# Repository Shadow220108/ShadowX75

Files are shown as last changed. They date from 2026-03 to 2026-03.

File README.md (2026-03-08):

# ShadowX75
It is a 75% layout, mechanical keyboard with hot-swap sockets! A rotatory encoder and an OLED screen!  

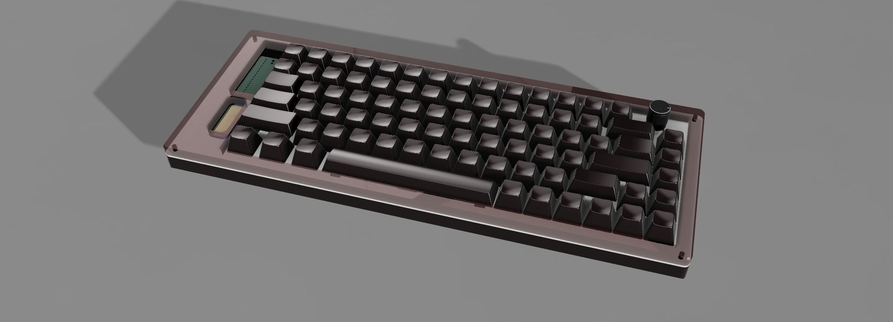
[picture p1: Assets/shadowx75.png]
ShadowX75
  

I made this project because I love keyboards. This would be my second keyboard after a split one! This version runs on QMK firmware and also has a rotatory encoder with an OLED screen  

### PCB
The PCB is designed to be compatible with Cherry MX switches and features hot-swappable kalih sockets.
| Schematics |
| --- |
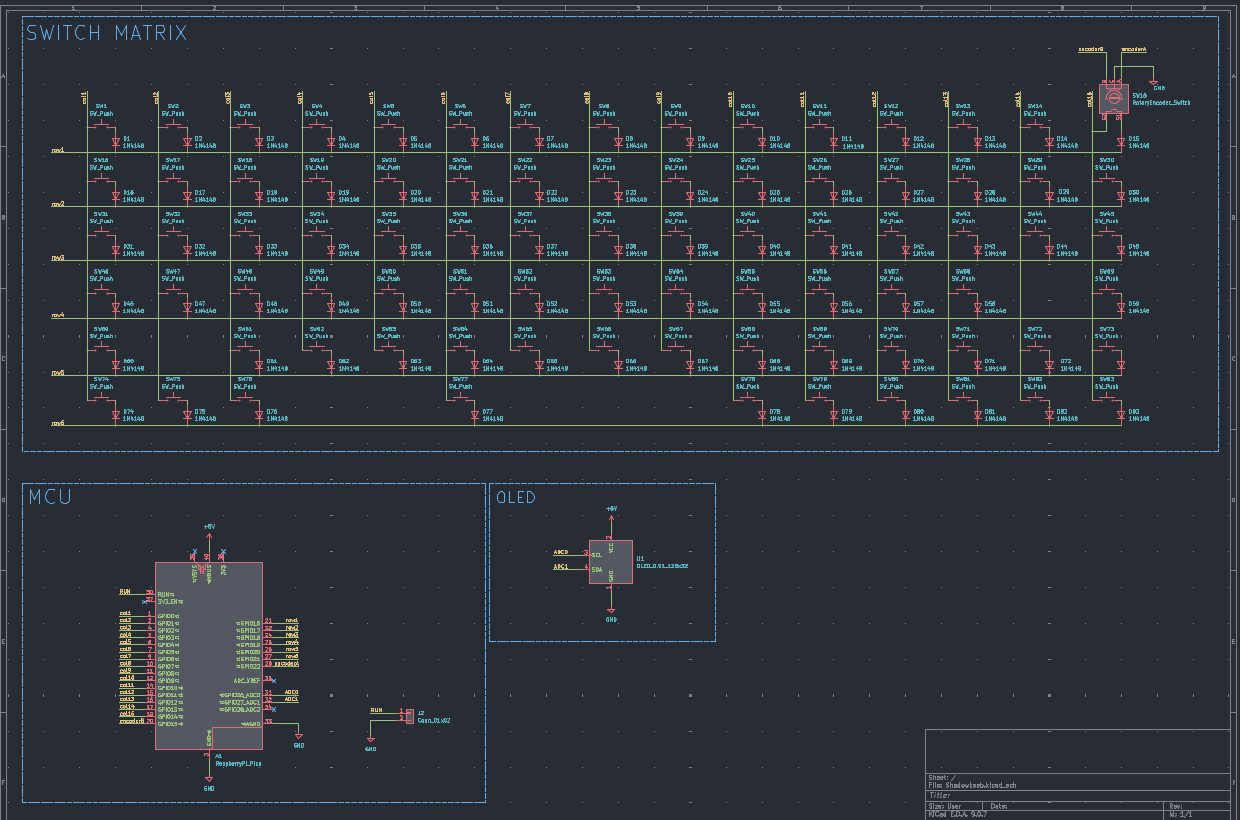
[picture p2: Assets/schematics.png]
Schematics
|  | 

| PCB (All Layers)|
| --- |
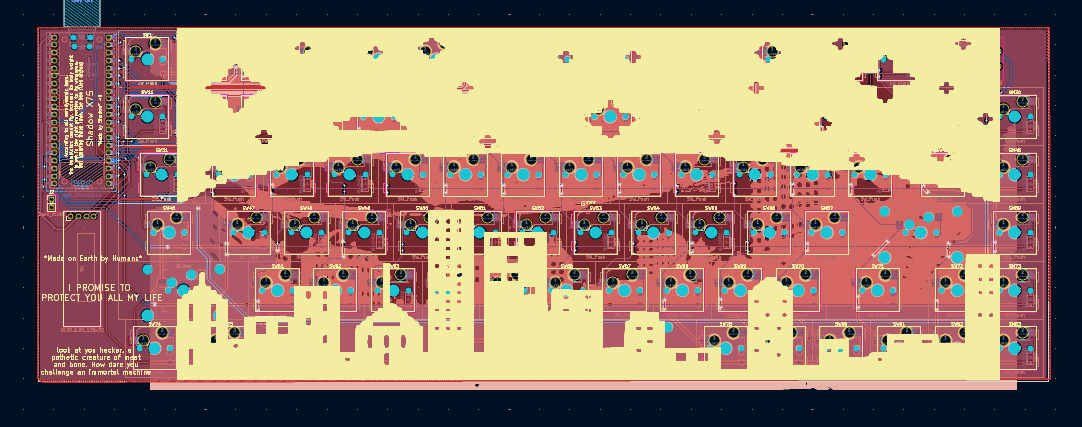
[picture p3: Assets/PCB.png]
PCB All Layers
|  |

| PCB (Without the art and zones)|
| --- |
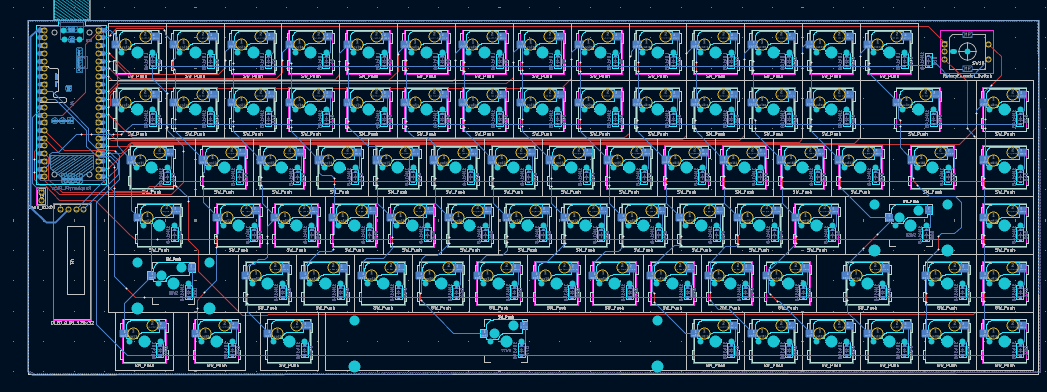
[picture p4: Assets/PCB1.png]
PCB1
|  |

| PS : Some PCB art|
| --- |
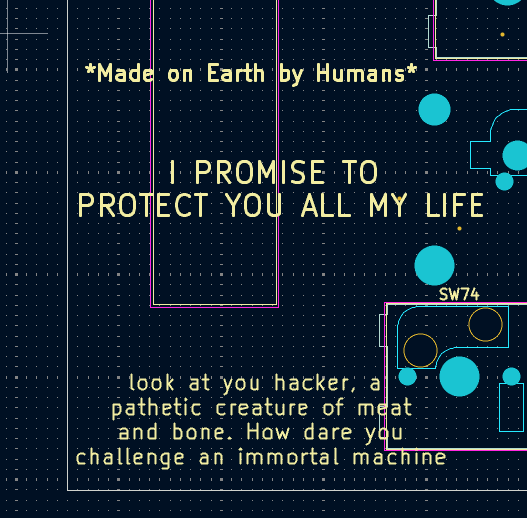
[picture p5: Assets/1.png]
|  |
| --- |
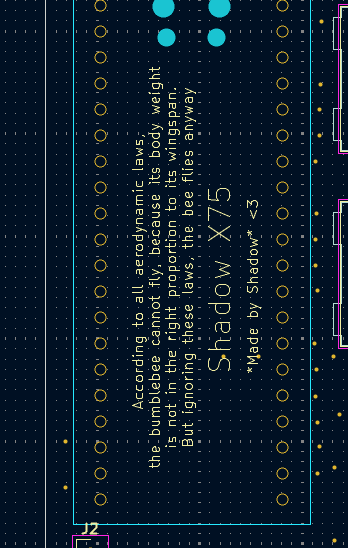
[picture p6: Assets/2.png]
|  |

## Case

The case is designed to be 3D printed and features a sandwich mount design with a 5° typing angle. The bottom case, top case, plate, and knob are all designed to be printed.

| Case Full|
| --- |
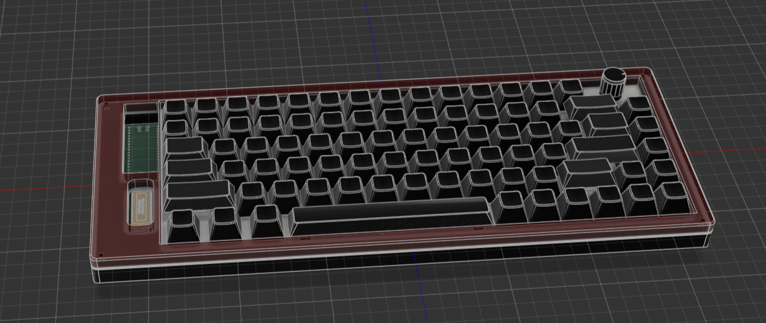
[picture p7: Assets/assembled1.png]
|  |

| Case Exploded View|
| --- |
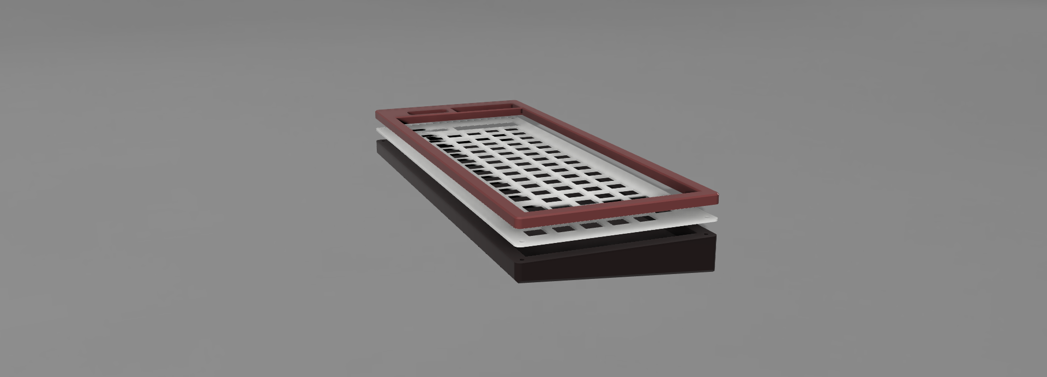
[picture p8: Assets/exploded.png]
|  |

## BOM ( I already have the parts mentioned as self sourced )
|Name |Purpose |Cost (USD)|Qty|Total (USD) |Link |Distributor |
|---|---|---|---|---|---|---|
| | | | | | | |
|Hotswap sockets |To solder to the PCB for switches |$0.11 |90 |$9.90 |[Link to Listing](https://stackskb.com/store/gateron-hotswap-sockets/)|Stackskb |
|PCB ( 5 MOQ ) |this is the main circuit board for keyboard |$40.00 |1  |$40.00 |- |JLCPCB |
|Stabilzers |To support the 2u and 6.25u keys |$0.00 |1  |$0.00 |- |Self sourced ( I already have the parts mentioned as self sourced )|
|Heatset inserts and Screws  |To attach the 3 bodies together |$0.00 |8  |$0.00 |- |Self sourced |
|Rotatory Encoder |To control volume/brightness |$0.00 |1  |$0.00 |- |Self sourced |
|OLED ( 0.91 inch ) |To display random stuff while I type |$0.00 |1  |$0.00 |- |Self sourced |
|Shipping charges |Shipping charge to get the 3d prints ( from #printing-legion )|$6.00 |1  |$6.00 |- |#printing-legion |
|Pin headers ( 1x40 ) |To solder the rpi pico to the PCB |$0.01 |1  |$0.01 |[Link to Listing](https://robu.in/product/2-54mm-1x40-pin-male-single-row-straight-short-header-strip-pack-of-3/)|robu.in |
|raspberry pi pico |This is the MCU of the keyboard |$4.50 |1  |$4.50 |[Link to Listing](https://robu.in/product/raspberry-pi-pico/)|robu.in |
|1N4148W SOD-123 1206 Diode  |Used for the matrix wiring in the keyboard |$0.01 |100|$0.92 |[Link to Listing](https://robu.in/product/1n4148w-sod-123-1206-diodereel-of-3000/)|robu.in |
|Keycap set ( Full Keyboard )|To add on the switches |$14.14 |1  |$14.14 |[Link to Listing](https://stackskb.com/store/veekos-gradient-keycaps-cherry-profile-135-keys/?attribute_pa_colour=rose-latte)|Stackskb |
|Switches |To press the keys |$0.26 |90 |$23.40 |[Link to Listing](https://stackskb.com/store/akko-piano-pro-switch-pack-of-45/)|Stackskb |
| | | | | | | |
| | | | |Total Estimated Cost (USD):$98.87| | |

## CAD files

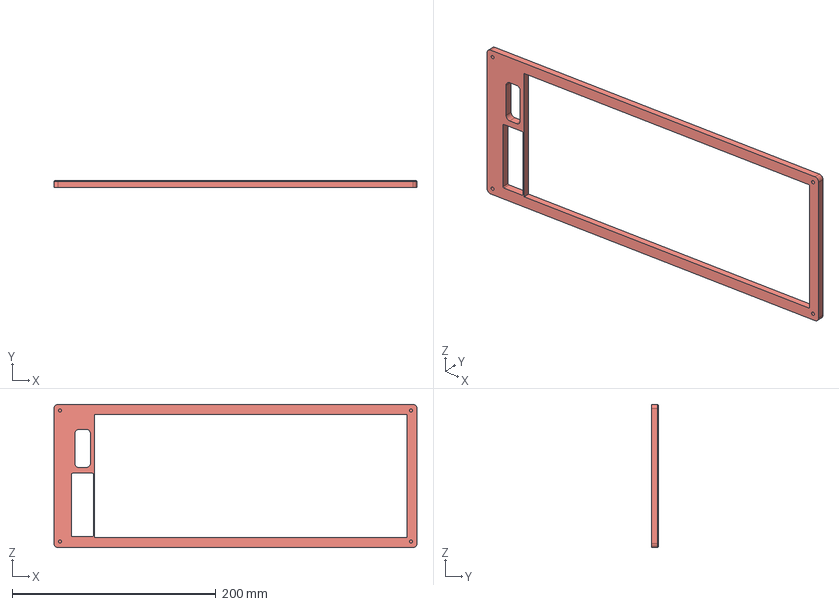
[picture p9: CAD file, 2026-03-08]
CAD/top.step
356.5 x 7.00 x 140.7 mm

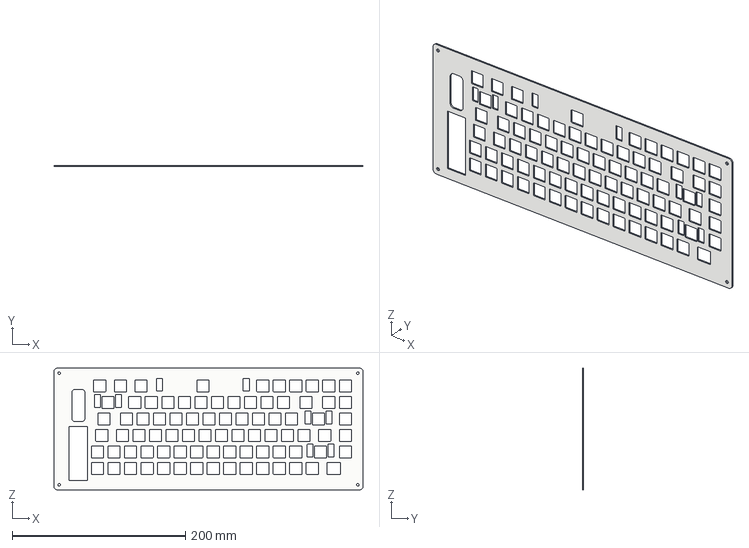
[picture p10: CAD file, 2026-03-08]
CAD/middle.step
356.5 x 1.50 x 140.7 mm

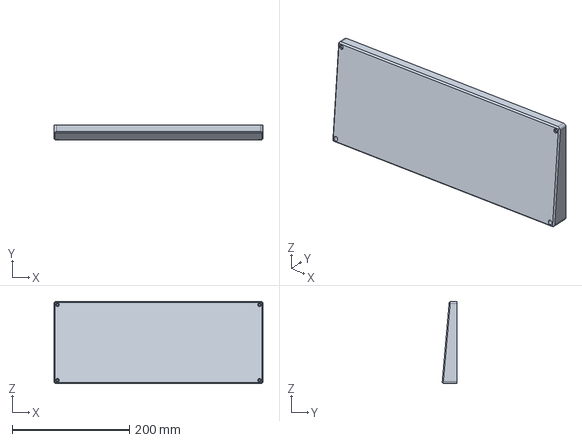
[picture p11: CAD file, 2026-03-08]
CAD/bottom.step
356.5 x 25.1 x 140.7 mm

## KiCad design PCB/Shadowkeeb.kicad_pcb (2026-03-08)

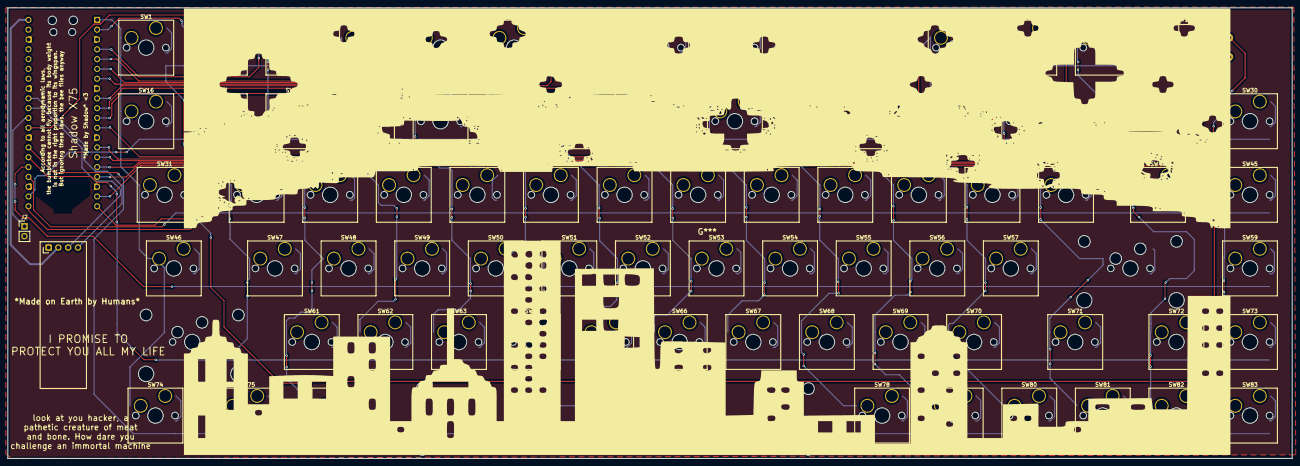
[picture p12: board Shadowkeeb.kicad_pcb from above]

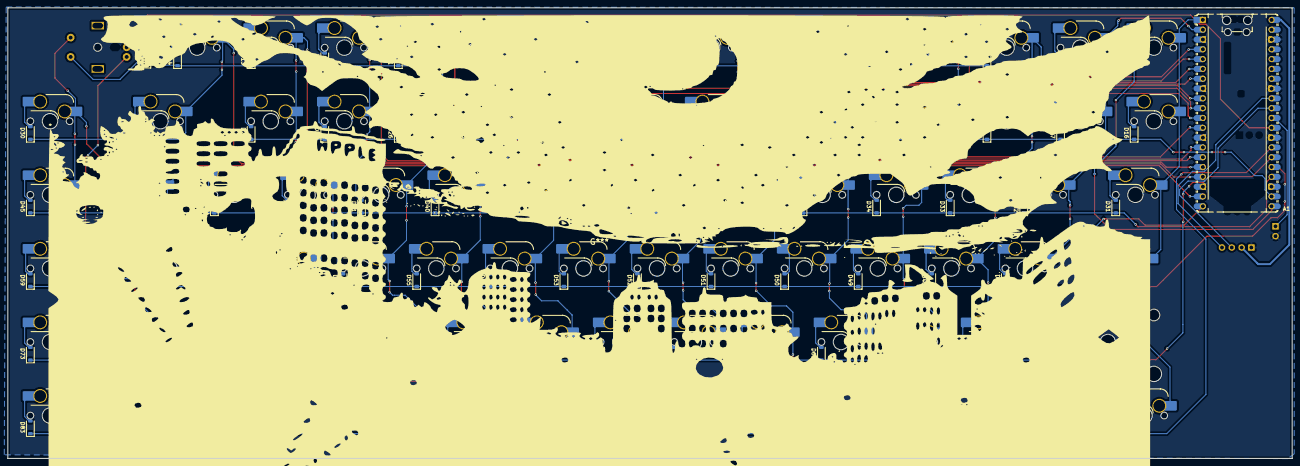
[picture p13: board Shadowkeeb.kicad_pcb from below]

Board: 2 copper layers, 332.5 x 116.7 mm, 169 parts (87 on the bottom side), 111 nets.

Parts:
A1: RaspberryPi_Pico; RaspberryPi_Pico_Common_Unspecified
D1, D2, D3, D4, D5, D6, D7, D8, D9, D10, D11, D12, D13, D14, D15, D16, D17, D18, D19, D20, D21, D22, D23, D24, D25, D26, D27, D28, D29, D30, D31, D32, D33, D34, D35, D36, D37, D38, D39, D40, D41, D42, D43, D44, D45, D46, D47, D48, D49, D50, D51, D52, D53, D54, D55, D56, D57, D58, D59, D60, D61, D62, D63, D64, D65, D66, D67, D68, D69, D70, D71, D72, D73, D74, D75, D76, D77, D78, D79, D80, D81, D82, D83: 1N4148; D_SOD-123
J2: Conn_01x02; PinHeader_1x02_P2.54mm_Vertical
SW1, SW2, SW3, SW4, SW5, SW6, SW7, SW8, SW9, SW10, SW11, SW12, SW13, SW14, SW16, SW17, SW18, SW19, SW20, SW21, SW22, SW23, SW24, SW25, SW26, SW27, SW28, SW30, SW32, SW33, SW34, SW35, SW36, SW37, SW38, SW39, SW40, SW41, SW42, SW43, SW45, SW47, SW48, SW49, SW50, SW51, SW52, SW53, SW54, SW55, SW56, SW57, SW59, SW61, SW62, SW63, SW64, SW65, SW66, SW67, SW68, SW69, SW70, SW72, SW73, SW74, SW75, SW76, SW78, SW79, SW80, SW81, SW82, SW83: SW_Push; SW_Hotswap_Kailh_MX_Plated_1.00u_With_Switch
SW15: RotaryEncoder_Switch; RotaryEncoder_Alps_EC11E-Switch_Vertical_H20mm_MountingHoles
SW29: SW_Push; SW_Hotswap_Kailh_MX_Plated_2.00u_With_Switch
SW31, SW44: SW_Push; SW_Hotswap_Kailh_MX_Plated_1.50u_With_Switch
SW46, SW71: SW_Push; SW_Hotswap_Kailh_MX_Plated_1.75u_With_Switch
SW58, SW60: SW_Push; MX-Hotswap-2.25U
SW77: SW_Push; MX-Hotswap-6.25U
U1: OLED_0.91_128x32

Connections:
+5V: A1.40 (VBUS), U1.2 (VCC)
/ADC0: A1.31 (GPIO26_ADC0), U1.3 (SCL)
/ADC1: A1.32 (GPIO27_ADC1), U1.4 (SDA)
/RUN: A1.30 (RUN), J2.1
/col1: A1.1 (GPIO0), SW1.1, SW16.1, SW31.1, SW46.1, SW60.1, SW74.1
/col2: A1.2 (GPIO1), SW2.1, SW17.1, SW32.1, SW47.1, SW75.1
/col3: A1.4 (GPIO2), SW3.1, SW18.1, SW33.1, SW48.1, SW61.1, SW76.1
/col4: A1.5 (GPIO3), SW4.1, SW19.1, SW34.1, SW49.1, SW62.1
/col5: A1.6 (GPIO4), SW5.1, SW20.1, SW35.1, SW50.1, SW63.1
/col6: A1.7 (GPIO5), SW6.1, SW21.1, SW36.1, SW51.1, SW64.1, SW77.1
/col7: A1.9 (GPIO6), SW7.1, SW22.1, SW37.1, SW52.1, SW65.1
/col8: A1.10 (GPIO7), SW8.1, SW23.1, SW38.1, SW53.1, SW66.1
/col9: A1.11 (GPIO8), SW9.1, SW24.1, SW39.1, SW54.1, SW67.1
/col10: A1.12 (GPIO9), SW10.1, SW25.1, SW40.1, SW55.1, SW68.1, SW78.1
/col11: A1.14 (GPIO10), SW11.1, SW26.1, SW41.1, SW56.1, SW69.1, SW79.1
/col12: A1.15 (GPIO11), SW12.1, SW27.1, SW42.1, SW57.1, SW70.1, SW80.1
/col13: A1.16 (GPIO12), SW13.1, SW28.1, SW43.1, SW58.1, SW71.1, SW81.1
/col14: A1.17 (GPIO13), SW14.1, SW29.1, SW44.1, SW72.1, SW82.1
/col15: A1.19 (GPIO14), SW15.S2, SW30.1, SW45.1, SW59.1, SW73.1, SW83.1
/encoderA: A1.29 (GPIO22), SW15.A
/encoderB: A1.20 (GPIO15), SW15.B
/row1: A1.21 (GPIO16), D1.1 (K), D2.1 (K), D3.1 (K), D4.1 (K), D5.1 (K), D6.1 (K), D7.1 (K), D8.1 (K), D9.1 (K), D10.1 (K), D11.1 (K), D12.1 (K), D13.1 (K), D14.1 (K), D15.1 (K)
/row2: A1.22 (GPIO17), D16.1 (K), D17.1 (K), D18.1 (K), D19.1 (K), D20.1 (K), D21.1 (K), D22.1 (K), D23.1 (K), D24.1 (K), D25.1 (K), D26.1 (K), D27.1 (K), D28.1 (K), D29.1 (K), D30.1 (K)
/row3: A1.24 (GPIO18), D31.1 (K), D32.1 (K), D33.1 (K), D34.1 (K), D35.1 (K), D36.1 (K), D37.1 (K), D38.1 (K), D39.1 (K), D40.1 (K), D41.1 (K), D42.1 (K), D43.1 (K), D44.1 (K), D45.1 (K)
/row4: A1.25 (GPIO19), D46.1 (K), D47.1 (K), D48.1 (K), D49.1 (K), D50.1 (K), D51.1 (K), D52.1 (K), D53.1 (K), D54.1 (K), D55.1 (K), D56.1 (K), D57.1 (K), D58.1 (K), D59.1 (K)
/row5: A1.26 (GPIO20), D60.1 (K), D61.1 (K), D62.1 (K), D63.1 (K), D64.1 (K), D65.1 (K), D66.1 (K), D67.1 (K), D68.1 (K), D69.1 (K), D70.1 (K), D71.1 (K), D72.1 (K), D73.1 (K)
/row6: A1.27 (GPIO21), D74.1 (K), D75.1 (K), D76.1 (K), D77.1 (K), D78.1 (K), D79.1 (K), D80.1 (K), D81.1 (K), D82.1 (K), D83.1 (K)
GND: A1.3 (GND), A1.8 (GND), A1.13 (GND), A1.18 (GND), A1.23 (GND), A1.28 (GND), A1.33 (AGND), A1.38 (GND), J2.2, SW15.C, U1.1 (GND)
unnamed: D1.2 (A), SW1.2
unnamed: D2.2 (A), SW2.2
unnamed: D3.2 (A), SW3.2
unnamed: D4.2 (A), SW4.2
unnamed: D5.2 (A), SW5.2
unnamed: D6.2 (A), SW6.2
unnamed: D7.2 (A), SW7.2
unnamed: D8.2 (A), SW8.2
unnamed: D9.2 (A), SW9.2
unnamed: D10.2 (A), SW10.2
unnamed: D11.2 (A), SW11.2
unnamed: D12.2 (A), SW12.2
unnamed: D13.2 (A), SW13.2
unnamed: D14.2 (A), SW14.2
unnamed: D15.2 (A), SW15.S1
unnamed: D16.2 (A), SW16.2
unnamed: D17.2 (A), SW17.2
unnamed: D18.2 (A), SW18.2
unnamed: D19.2 (A), SW19.2
unnamed: D20.2 (A), SW20.2
unnamed: D21.2 (A), SW21.2
unnamed: D22.2 (A), SW22.2
unnamed: D23.2 (A), SW23.2
unnamed: D24.2 (A), SW24.2
unnamed: D25.2 (A), SW25.2
unnamed: D26.2 (A), SW26.2
unnamed: D27.2 (A), SW27.2
unnamed: D28.2 (A), SW28.2
unnamed: D29.2 (A), SW29.2
unnamed: D30.2 (A), SW30.2
unnamed: D31.2 (A), SW31.2
unnamed: D32.2 (A), SW32.2
unnamed: D33.2 (A), SW33.2
unnamed: D34.2 (A), SW34.2
unnamed: D35.2 (A), SW35.2
unnamed: D36.2 (A), SW36.2
unnamed: D37.2 (A), SW37.2
unnamed: D38.2 (A), SW38.2
unnamed: D39.2 (A), SW39.2
unnamed: D40.2 (A), SW40.2
unnamed: D41.2 (A), SW41.2
unnamed: D42.2 (A), SW42.2
unnamed: D43.2 (A), SW43.2
unnamed: D44.2 (A), SW44.2
unnamed: D45.2 (A), SW45.2
unnamed: D46.2 (A), SW46.2
unnamed: D47.2 (A), SW47.2
unnamed: D48.2 (A), SW48.2
unnamed: D49.2 (A), SW49.2
unnamed: D50.2 (A), SW50.2
unnamed: D51.2 (A), SW51.2
unnamed: D52.2 (A), SW52.2
unnamed: D53.2 (A), SW53.2
unnamed: D54.2 (A), SW54.2
unnamed: D55.2 (A), SW55.2
unnamed: D56.2 (A), SW56.2
unnamed: D57.2 (A), SW57.2
unnamed: D58.2 (A), SW58.2
unnamed: D59.2 (A), SW59.2
unnamed: D60.2 (A), SW60.2
unnamed: D61.2 (A), SW61.2
unnamed: D62.2 (A), SW62.2
unnamed: D63.2 (A), SW63.2
unnamed: D64.2 (A), SW64.2
unnamed: D65.2 (A), SW65.2
unnamed: D66.2 (A), SW66.2
unnamed: D67.2 (A), SW67.2
unnamed: D68.2 (A), SW68.2
unnamed: D69.2 (A), SW69.2
unnamed: D70.2 (A), SW70.2
unnamed: D71.2 (A), SW71.2
unnamed: D72.2 (A), SW72.2
unnamed: D73.2 (A), SW73.2
unnamed: D74.2 (A), SW74.2
unnamed: D75.2 (A), SW75.2
unnamed: D76.2 (A), SW76.2
unnamed: D77.2 (A), SW77.2
unnamed: D78.2 (A), SW78.2
unnamed: D79.2 (A), SW79.2
unnamed: D80.2 (A), SW80.2
unnamed: D81.2 (A), SW81.2
unnamed: D82.2 (A), SW82.2
unnamed: D83.2 (A), SW83.2

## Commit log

2026-03-08 Uploading files from local repo
    [Shadowkeeb.kicad_pcb, bottom.step, middle.step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]
2026-03-08 Added BOM.csv
    [BOM.csv]
